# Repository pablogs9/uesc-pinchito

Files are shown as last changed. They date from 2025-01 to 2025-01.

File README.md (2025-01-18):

# uESC pinchito edition

An evolution of the uESC from the
[rcgroups.com forum](https://www.rcgroups.com/forums/showthread.php?2971342-uESC-World-smallest-1S-BLHeli_S-ESC)
by user [nppc](https://github.com/nppc).
Redesign by [Pablo Garrido](https://github.com/pablogs9).

Components are only on the top face for SMT.

Not optimized by size or weight yet.

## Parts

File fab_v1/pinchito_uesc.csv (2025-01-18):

Reference | Value | LCSC Part
C1 | 47u | C16780
C2 | 10u | C15850
C3 | 100n | C28233
J1,J2 | Conn_01x03_Pin
Q1,Q2,Q3 | AO6604_C709896 | C709896
Q4,Q5,Q6 | AO6604_C5182068 | C5182068
R1,R2,R4,R8 | 1k | C21190
R3,R5,R6 | 10k | C25804
TP1,TP2 | TestPoint
U1 | EFM8BB21F16G-C-QFN20 | C80713

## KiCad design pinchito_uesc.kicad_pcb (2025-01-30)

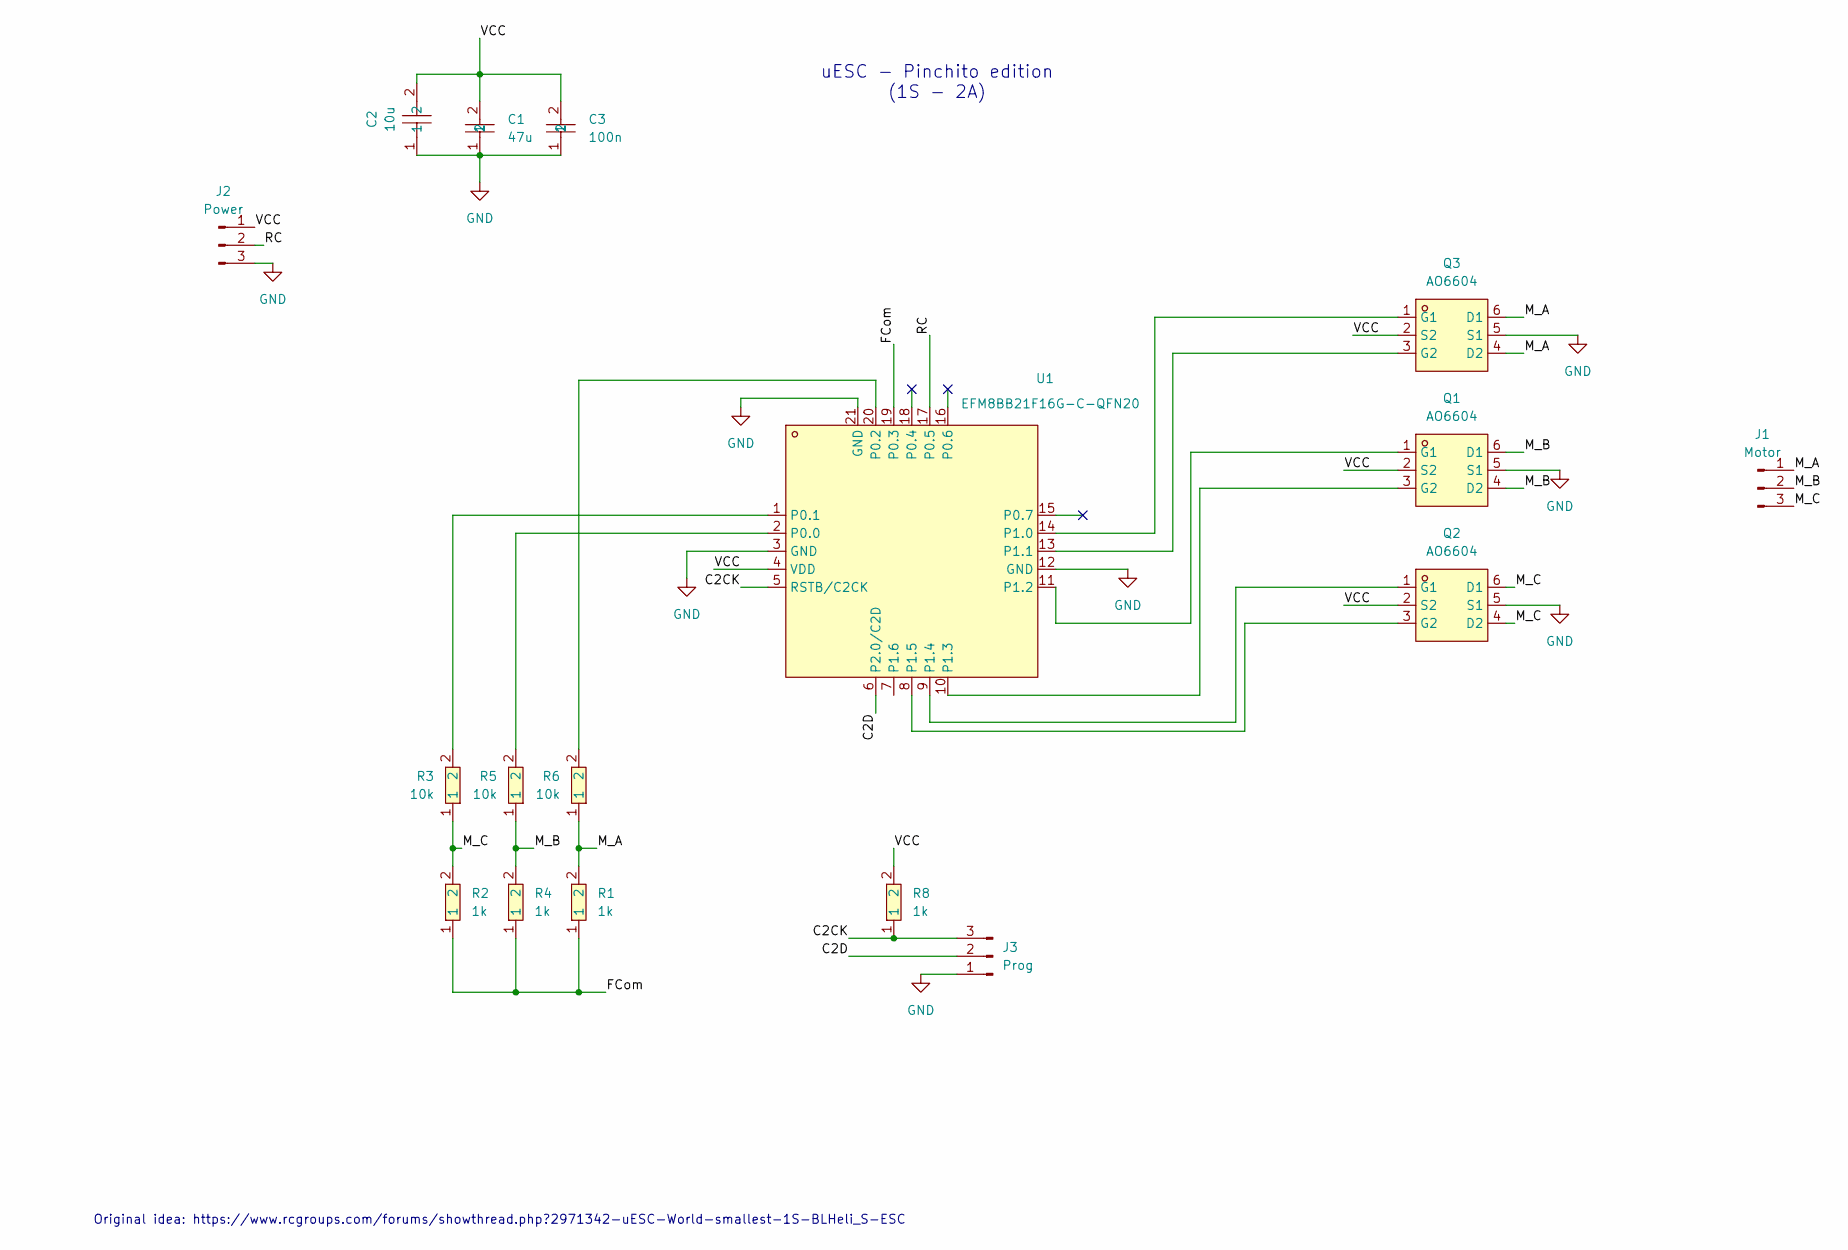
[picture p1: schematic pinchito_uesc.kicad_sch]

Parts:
C1: 47u; C0805; LCSC Part C16780
C2: 10u; C0805; LCSC Part C15850
C3: 100n; C0805; LCSC Part C28233
J1: Motor; PinHeader_1x03_P2.00mm_Vertical
J2: Power; PinHeader_1x03_P2.00mm_Vertical
J3: Prog; PinHeader_1x03_P2.00mm_Vertical
Q1, Q2, Q3: AO6604; TSOP-6_L3.0-W1.5-P0.95-LS2.8-BR; LCSC Part C47744
R1, R2, R4, R8: 1k; R0603; LCSC Part C21190
R3, R5, R6: 10k; R0603; LCSC Part C25804
U1: EFM8BB21F16G-C-QFN20; QFN-20_L3.0-W3.0-P0.50-BL-EP1.7_EFM8BB21F16G; LCSC Part C80713

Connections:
/C2CK: J3.3, R8.1, U1.5 (RSTB/C2CK)
/C2D: J3.2, U1.6 (P2.0/C2D)
/FCom: R1.1, R2.1, R4.1, U1.19 (P0.3)
/M_A: J1.1, Q3.4 (D2), Q3.6 (D1), R1.2, R6.1
/M_B: J1.2, Q1.4 (D2), Q1.6 (D1), R4.2, R5.1
/M_C: J1.3, Q2.4 (D2), Q2.6 (D1), R2.2, R3.1
/RC: J2.2, U1.17 (P0.5)
/VCC: C1.2, C2.2, C3.2, J2.1, Q1.2 (S2), Q2.2 (S2), Q3.2 (S2), R8.2, U1.4 (VDD)
GND: C1.1, C2.1, C3.1, J2.3, J3.1, Q1.5 (S1), Q2.5 (S1), Q3.5 (S1), U1.3 (GND), U1.12 (GND), U1.21 (GND)
unnamed: Q1.1 (G1), U1.11 (P1.2)
unnamed: Q1.3 (G2), U1.10 (P1.3)
unnamed: Q2.1 (G1), U1.9 (P1.4)
unnamed: Q2.3 (G2), U1.8 (P1.5)
unnamed: Q3.1 (G1), U1.14 (P1.0)
unnamed: Q3.3 (G2), U1.13 (P1.1)
unnamed: R5.2, U1.2 (P0.0)
unnamed: R3.2, U1.1 (P0.1)
unnamed: R6.2, U1.20 (P0.2)

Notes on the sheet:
uESC - Pinchito edition (1S - 2A)
Original idea: https://www.rcgroups.com/forums/showthread.php?2971342-uESC-World-smallest-1S-BLHeli_S-ESC

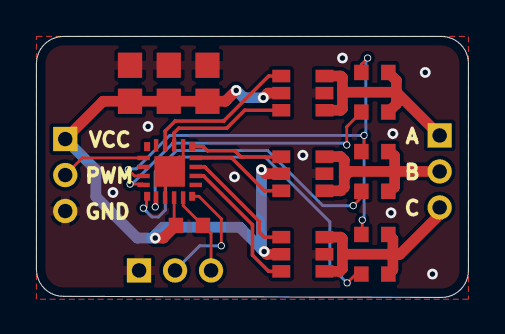
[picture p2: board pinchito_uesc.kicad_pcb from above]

Board: 2 copper layers, 24.0 x 14.5 mm, 17 parts (0 on the bottom side), 18 nets.

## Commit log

2025-01-18 Add Fab V1
    [pinchito_uesc-CmtUser.gbr, pinchito_uesc-CuBottom.gbl, pinchito_uesc-CuTop.gtl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]
2025-01-29 Bump design to new MOSFETs
    [pinchito_uesc.kicad_pcb, pinchito_uesc.kicad_sch]
2025-01-29 Round Corners
    [pinchito_uesc.kicad_pcb]
2025-01-30 Fix Via size to .3/.4 mm
    [pinchito_uesc.kicad_pcb]
